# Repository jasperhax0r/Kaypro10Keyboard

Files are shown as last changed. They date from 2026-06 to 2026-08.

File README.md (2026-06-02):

# Kaypro 10 Replacement Keyboard

A modern replacement keyboard for the Kaypro 10 that fits the original case, using Cherry MX-style switches and a Raspberry Pi Pico running MicroPython to emulate the original 300 baud serial keyboard interface.

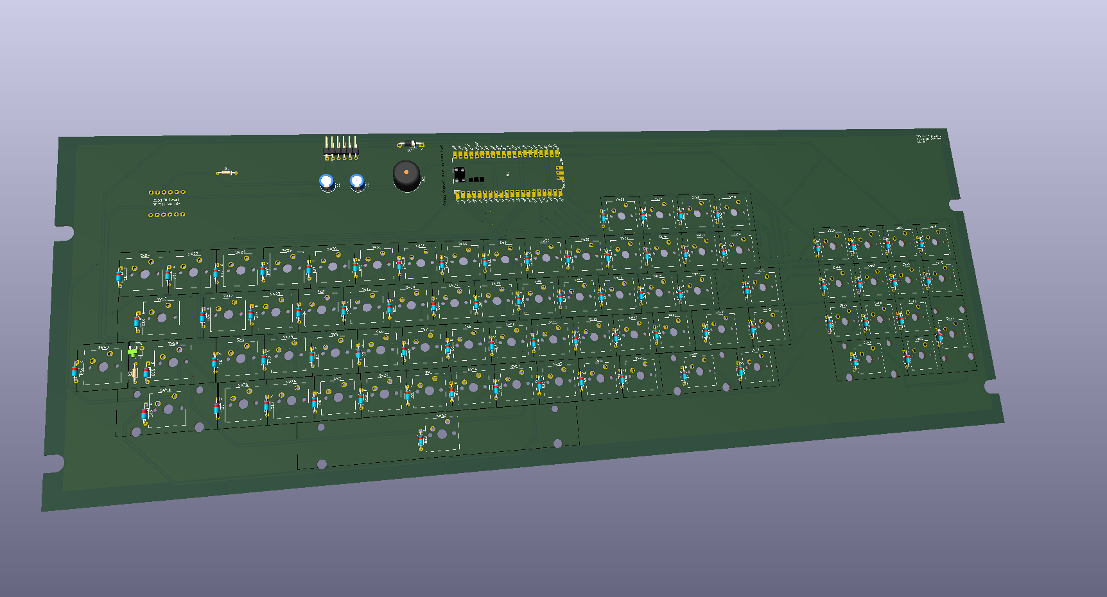
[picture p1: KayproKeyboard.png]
Kaypro Keyboard PCB


*KiCad 3D render of the PCB*

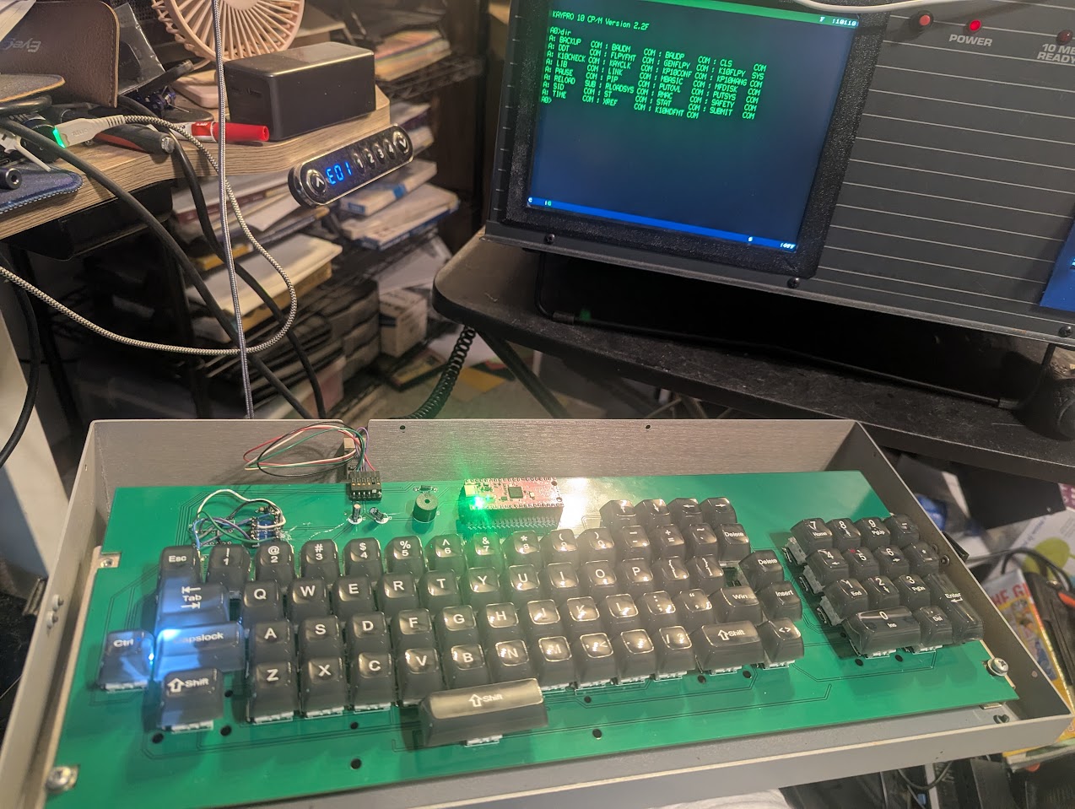
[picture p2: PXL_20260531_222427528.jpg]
Prototype Working


*Prototype board installed and working*

---

## Overview

The original Kaypro 10 keyboard is increasingly difficult to find in working condition. This project provides a drop-in replacement that:

- Fits the original Kaypro 10 keyboard case with no modifications
- Uses modern Cherry MX-style mechanical switches
- Communicates over the Kaypro's original 300 baud serial keyboard interface
- Is driven by a Raspberry Pi Pico running MicroPython
- Includes a 3D printed switch support plate (no metal plate in this design)

---

## Repository Contents

All files are in the root of the repository.

| File | Description |
|---|---|
| `*.kicad_pro`, `*.kicad_sch`, `*.kicad_pcb`, etc. | KiCad 10 schematic and PCB design files |
| `KayproKeyboard.zip` | Generated Gerber/manufacturing files, ready to send to a PCB fab |
| `KayproKeyboard.png` | KiCad 3D render of the board |
| `keyboard support.stl` | 3D printable switch support plate |
| `main.py` | MicroPython firmware for the Raspberry Pi Pico |
| `PXL_20260531_222427528.jpg` | Photo of the working prototype |

---

## Bill of Materials

| Qty | Component | Notes |
|-----|---|---|
| 76 | 1N4148 diode | One per switch, for key matrix decoding |
| 76 | Cherry MX-style switches | One per key position |
| — | PCB-mount stabilizers | Required for larger keys (spacebar, shift, enter, etc.) — quantity depends on layout |
| 1 | Waveshare BS138 4-channel bidirectional level shifter module | 3.3V ↔ 5V logic level conversion |
| 1 | Passive buzzer/speaker | Key click feedback |
| 1 | LED (single, any color) | Status indicator |
| 1 | 330Ω resistor | LED current limiting |
| 1 | 47kΩ resistor | Pull-up/pull-down for serial line |
| 1 | Protection diode | 5V input protection for the Pico |
| 1 | Raspberry Pi Pico | Main controller (standard Pico, not Pico W) |
| 1 | 6-pin horizontal header | Serial interface connector to Kaypro mainboard |

> **Note:** Use 1N4148 diodes (or equivalent) for the key matrix. One diode is required per switch to prevent ghosting.

---

## PCB Manufacturing

The file `KayproKeyboard.zip` contains all Gerber files needed for fabrication. It can be uploaded directly to most PCB manufacturers (JLCPCB, PCBWay, OSHPark, etc.) without modification.

Recommended specs:
- **Layers:** 2
- **Thickness:** 1.6mm
- **Surface finish:** HASL or ENIG

---

## 3D Printed Support

Because this design does not use a metal switch plate, a 3D printed support structure (`keyboard support.stl`) is included to provide rigidity and hold the switches in alignment during soldering and use.

Print in PLA or PETG at 0.2mm layer height with at least 20% infill. No supports should be needed.

---

## Firmware

The Pico runs MicroPython. Copy `main.py` to the Pico's root filesystem and it will start automatically on boot.

### Flashing the Pico

1. Hold the BOOTSEL button and connect the Pico to your computer via USB.
2. It will appear as a USB mass storage device (`RPI-RP2`).
3. Flash the latest [MicroPython UF2](https://micropython.org/download/rp2-pico/) by dragging it onto the drive.
4. Once rebooted, use a tool like [Thonny](https://thonny.org/) or `mpremote` to copy `main.py` to the Pico:
   ```
   mpremote cp main.py :main.py
   ```

The firmware reads the key matrix, debounces inputs, and outputs the correct character codes over the serial interface at 300 baud to match the Kaypro's original keyboard protocol.

---

## Connector Pinout

The keyboard connects to the Kaypro 10 mainboard via a 6-pin horizontal header. Pinout, numbered left to right:

| Pin | Signal | Description |
|-----|---|---|
| 1 | 5V | Power from Kaypro mainboard |
| 2 | TX | Serial data out — keyboard → Kaypro, 300 baud |
| 3 | GND | Ground |
| 4 | GND | Ground |
| 5 | — | Missing/keyed pin (no connection) |
| 6 | RX | Serial data in — Kaypro → keyboard, 300 baud |

> ⚠️ **Important:** This pinout was determined from an **1983-spec Kaypro 10**. It may not be universal across all Kaypro models or revisions. Verify against your own machine before connecting. The protection diode on the 5V input and the BS138 level shifter are strongly recommended to avoid damaging the Pico.

The BS138 level shifter module handles 3.3V Pico ↔ 5V Kaypro logic translation on the TX and RX lines.

---

## Design Files

Schematics and PCB layout were created in **KiCad 10**. The KiCad project files are in the root directory and can be opened and modified freely.

---

## License

This project is open source. Schematics, PCB files, firmware, and mechanical files are provided as-is for personal and educational use.

Contributions, improvements, and ports to other Kaypro models are welcome — open a PR or issue!

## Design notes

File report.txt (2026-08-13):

Info: X scale constrained.
Info: Y scale constrained.
Plotted to 'C:\Users\Jasper\Desktop\Projects\Kaypro10\3D Prints and PCBs\KayproKeyboard\KayproKeyboard-F_Cu.gbr'.
Plotted to 'C:\Users\Jasper\Desktop\Projects\Kaypro10\3D Prints and PCBs\KayproKeyboard\KayproKeyboard-B_Cu.gbr'.
Plotted to 'C:\Users\Jasper\Desktop\Projects\Kaypro10\3D Prints and PCBs\KayproKeyboard\KayproKeyboard-F_Paste.gbr'.
Plotted to 'C:\Users\Jasper\Desktop\Projects\Kaypro10\3D Prints and PCBs\KayproKeyboard\KayproKeyboard-B_Paste.gbr'.
Plotted to 'C:\Users\Jasper\Desktop\Projects\Kaypro10\3D Prints and PCBs\KayproKeyboard\KayproKeyboard-F_Silkscreen.gbr'.
Plotted to 'C:\Users\Jasper\Desktop\Projects\Kaypro10\3D Prints and PCBs\KayproKeyboard\KayproKeyboard-B_Silkscreen.gbr'.
Plotted to 'C:\Users\Jasper\Desktop\Projects\Kaypro10\3D Prints and PCBs\KayproKeyboard\KayproKeyboard-F_Mask.gbr'.
Plotted to 'C:\Users\Jasper\Desktop\Projects\Kaypro10\3D Prints and PCBs\KayproKeyboard\KayproKeyboard-B_Mask.gbr'.
Plotted to 'C:\Users\Jasper\Desktop\Projects\Kaypro10\3D Prints and PCBs\KayproKeyboard\KayproKeyboard-Edge_Cuts.gbr'.
Created Gerber job file 'C:\Users\Jasper\Desktop\Projects\Kaypro10\3D Prints and PCBs\KayproKeyboard\KayproKeyboard-job.gbrjob'.
Info: Done.

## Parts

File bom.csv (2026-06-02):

Designator | Footprint | Quantity | Value | LCSC Part #
BZ1 | Buzzer_12x9.5RM7.6 | 1 | Buzzer
C1, C2 | CP_Radial_D6.3mm_P2.50mm | 2 | C_Polarized_US
D1, D10, D11, D12, D13, D14, D15, D16, D17, D18, D19, D2, D20, D21, D22, D23, D24, D25, D26, D27, D28, D29, D3, D30, D31, D32, D33, D34, D35, D36, D37, D38, D39, D4, D40, D41, D42, D43, D44, D45, D46, D47, D48, D49, D5, D50, D51, D52, D53, D54, D55, D56, D57, D58, D59, D6, D60, D61, D62, D63, D64, D65, D66, D67, D68, D69, D7, D70, D71, D72, D73, D74, D75, D78, D8, D9 | D_DO-35_SOD27_P7.62mm_Horizontal | 76 | 1N4148
D76 | LED_D1.8mm_W1.8mm_H2.4mm_Horizontal_O1.27mm_Z4.9mm | 1 | CAPSLED
D77 | D_DO-41_SOD81_P10.16mm_Horizontal | 1 | 1N5817
J1 | PinHeader_1x06_P2.54mm_Horizontal | 1 | Conn_01x06_Pin
J2, J3 | 1x06_P2.54mm | 2 | Conn_01x06
R1 | R_Axial_DIN0204_L3.6mm_D1.6mm_P7.62mm_Horizontal | 1 | 4.7K
R2 | R_Axial_DIN0204_L3.6mm_D1.6mm_P7.62mm_Horizontal | 1 | 330
SW1 | SW_Cherry_MX_1.00u_PCB | 1 | A_Key
SW10 | SW_Cherry_MX_1.00u_PCB | 1 | J_Key
SW11 | SW_Cherry_MX_1.00u_PCB | 1 | K_Key
SW12 | SW_Cherry_MX_1.00u_PCB | 1 | L_Key
SW13 | SW_Cherry_MX_1.00u_PCB | 1 | M_Key
SW14 | SW_Cherry_MX_1.00u_PCB | 1 | N_Key
SW15 | SW_Cherry_MX_1.00u_PCB | 1 | O_Key
SW16 | SW_Cherry_MX_1.00u_PCB | 1 | P_Key
SW17 | SW_Cherry_MX_1.00u_PCB | 1 | Q_Key
SW18 | SW_Cherry_MX_1.00u_PCB | 1 | R_Key
SW19 | SW_Cherry_MX_1.00u_PCB | 1 | S_Key
SW2 | SW_Cherry_MX_1.00u_PCB | 1 | B_Key
SW20 | SW_Cherry_MX_1.00u_PCB | 1 | T_Key
SW21 | SW_Cherry_MX_1.00u_PCB | 1 | U_Key
SW22 | SW_Cherry_MX_1.00u_PCB | 1 | V_Key
SW23 | SW_Cherry_MX_1.00u_PCB | 1 | W_Key
SW24 | SW_Cherry_MX_1.00u_PCB | 1 | X_Key
SW25 | SW_Cherry_MX_1.00u_PCB | 1 | Y_Key
SW26 | SW_Cherry_MX_1.00u_PCB | 1 | Z_Key
SW27 | SW_Cherry_MX_1.00u_PCB | 1 | 1_Key
SW28 | SW_Cherry_MX_1.00u_PCB | 1 | 2_Key
SW29 | SW_Cherry_MX_1.00u_PCB | 1 | 3_Key
SW3 | SW_Cherry_MX_1.00u_PCB | 1 | C_Key
SW30 | SW_Cherry_MX_1.00u_PCB | 1 | 4_Key
SW31 | SW_Cherry_MX_1.00u_PCB | 1 | 5_Key
SW32 | SW_Cherry_MX_1.00u_PCB | 1 | 6_Key
SW33 | SW_Cherry_MX_1.00u_PCB | 1 | 7_Key
SW34 | SW_Cherry_MX_1.00u_PCB | 1 | 8_Key
SW35 | SW_Cherry_MX_1.00u_PCB | 1 | 9_Key
SW36 | SW_Cherry_MX_1.00u_PCB | 1 | 0_Key
SW37 | SW_Cherry_MX_1.00u_PCB | 1 | -_Key
SW38 | SW_Cherry_MX_1.00u_PCB | 1 | =_Key
SW39 | SW_Cherry_MX_1.00u_PCB | 1 | `_Key
SW4 | SW_Cherry_MX_1.00u_PCB | 1 | D_Key
SW40 | SW_Cherry_MX_1.00u_PCB | 1 | ;_Key
SW41 | SW_Cherry_MX_1.00u_PCB | 1 | '_Key
SW42 | SW_Cherry_MX_1.00u_PCB | 1 | \_Key
SW43 | SW_Cherry_MX_1.00u_PCB | 1 | ,_Key
SW44 | SW_Cherry_MX_1.00u_PCB | 1 | ._Key
SW45 | SW_Cherry_MX_1.00u_PCB | 1 | /_Key
SW46 | SW_Cherry_MX_2.00u_PCB | 1 | LSHIFT_Key
SW47 | SW_Cherry_MX_2.00u_PCB | 1 | RSHIFT_Key
SW49 | SW_Cherry_MX_1.00u_PCB | 1 | CTRL_Key
SW5 | SW_Cherry_MX_1.00u_PCB | 1 | E_Key
SW50 | SW_Cherry_MX_1.75u_PCB | 1 | CAPS_Key
SW51 | SW_Cherry_MX_1.00u_PCB | 1 | DEL_Key
SW52 | SW_Cherry_MX_1.00u_PCB | 1 | BACKSPACE_Key
SW53 | SW_Cherry_MX_6.25u_PCB | 1 | SPACE_Key
SW54 | SW_Cherry_MX_1.00u_PCB | 1 | ESC_Key
SW55 | SW_Cherry_MX_1.75u_PCB | 1 | TAB_Key
SW56 | SW_Cherry_MX_1.50u_PCB | 1 | RETURN_Key
SW57 | SW_Cherry_MX_1.00u_PCB | 1 | LINEFEED_Key
SW58 | SW_Cherry_MX_1.00u_PCB | 1 | UP_Key
SW59 | SW_Cherry_MX_1.00u_PCB | 1 | DOWN_Key
SW6 | SW_Cherry_MX_1.00u_PCB | 1 | F_Key
SW60 | SW_Cherry_MX_1.00u_PCB | 1 | LEFT_Key
SW61 | SW_Cherry_MX_1.00u_PCB | 1 | RIGHT_Key
SW62 | SW_Cherry_MX_2.00u_PCB | 1 | NUM0_Key
SW63 | SW_Cherry_MX_1.00u_PCB | 1 | NUM1_Key
SW64 | SW_Cherry_MX_1.00u_PCB | 1 | NUM2_Key
SW65 | SW_Cherry_MX_1.00u_PCB | 1 | NUM3_Key
SW66 | SW_Cherry_MX_1.00u_PCB | 1 | NUM4_Key
SW67 | SW_Cherry_MX_1.00u_PCB | 1 | NUM5_Key
SW68 | SW_Cherry_MX_1.00u_PCB | 1 | NUM6_Key
SW69 | SW_Cherry_MX_1.00u_PCB | 1 | NUM7_Key
SW7 | SW_Cherry_MX_1.00u_PCB | 1 | G_Key
SW70 | SW_Cherry_MX_1.00u_PCB | 1 | NUM8_Key
SW71 | SW_Cherry_MX_1.00u_PCB | 1 | NUM9_Key
SW72 | SW_Cherry_MX_1.00u_PCB | 1 | NUM._Key
SW73 | SW_Cherry_MX_2.00u_Vertical_PCB | 1 | NUMENTER_Key
SW74 | SW_Cherry_MX_1.00u_PCB | 1 | NUM-_Key
SW75 | SW_Cherry_MX_1.00u_PCB | 1 | NUM,_Key
SW76 | SW_Cherry_MX_1.00u_PCB | 1 | [_KEY
SW77 | SW_Cherry_MX_1.00u_PCB | 1 | ]_KEY
SW8 | SW_Cherry_MX_1.00u_PCB | 1 | H_Key
SW9 | SW_Cherry_MX_1.00u_PCB | 1 | I_Key
U1 | RPi_Pico_SMD_TH | 1 | Pico

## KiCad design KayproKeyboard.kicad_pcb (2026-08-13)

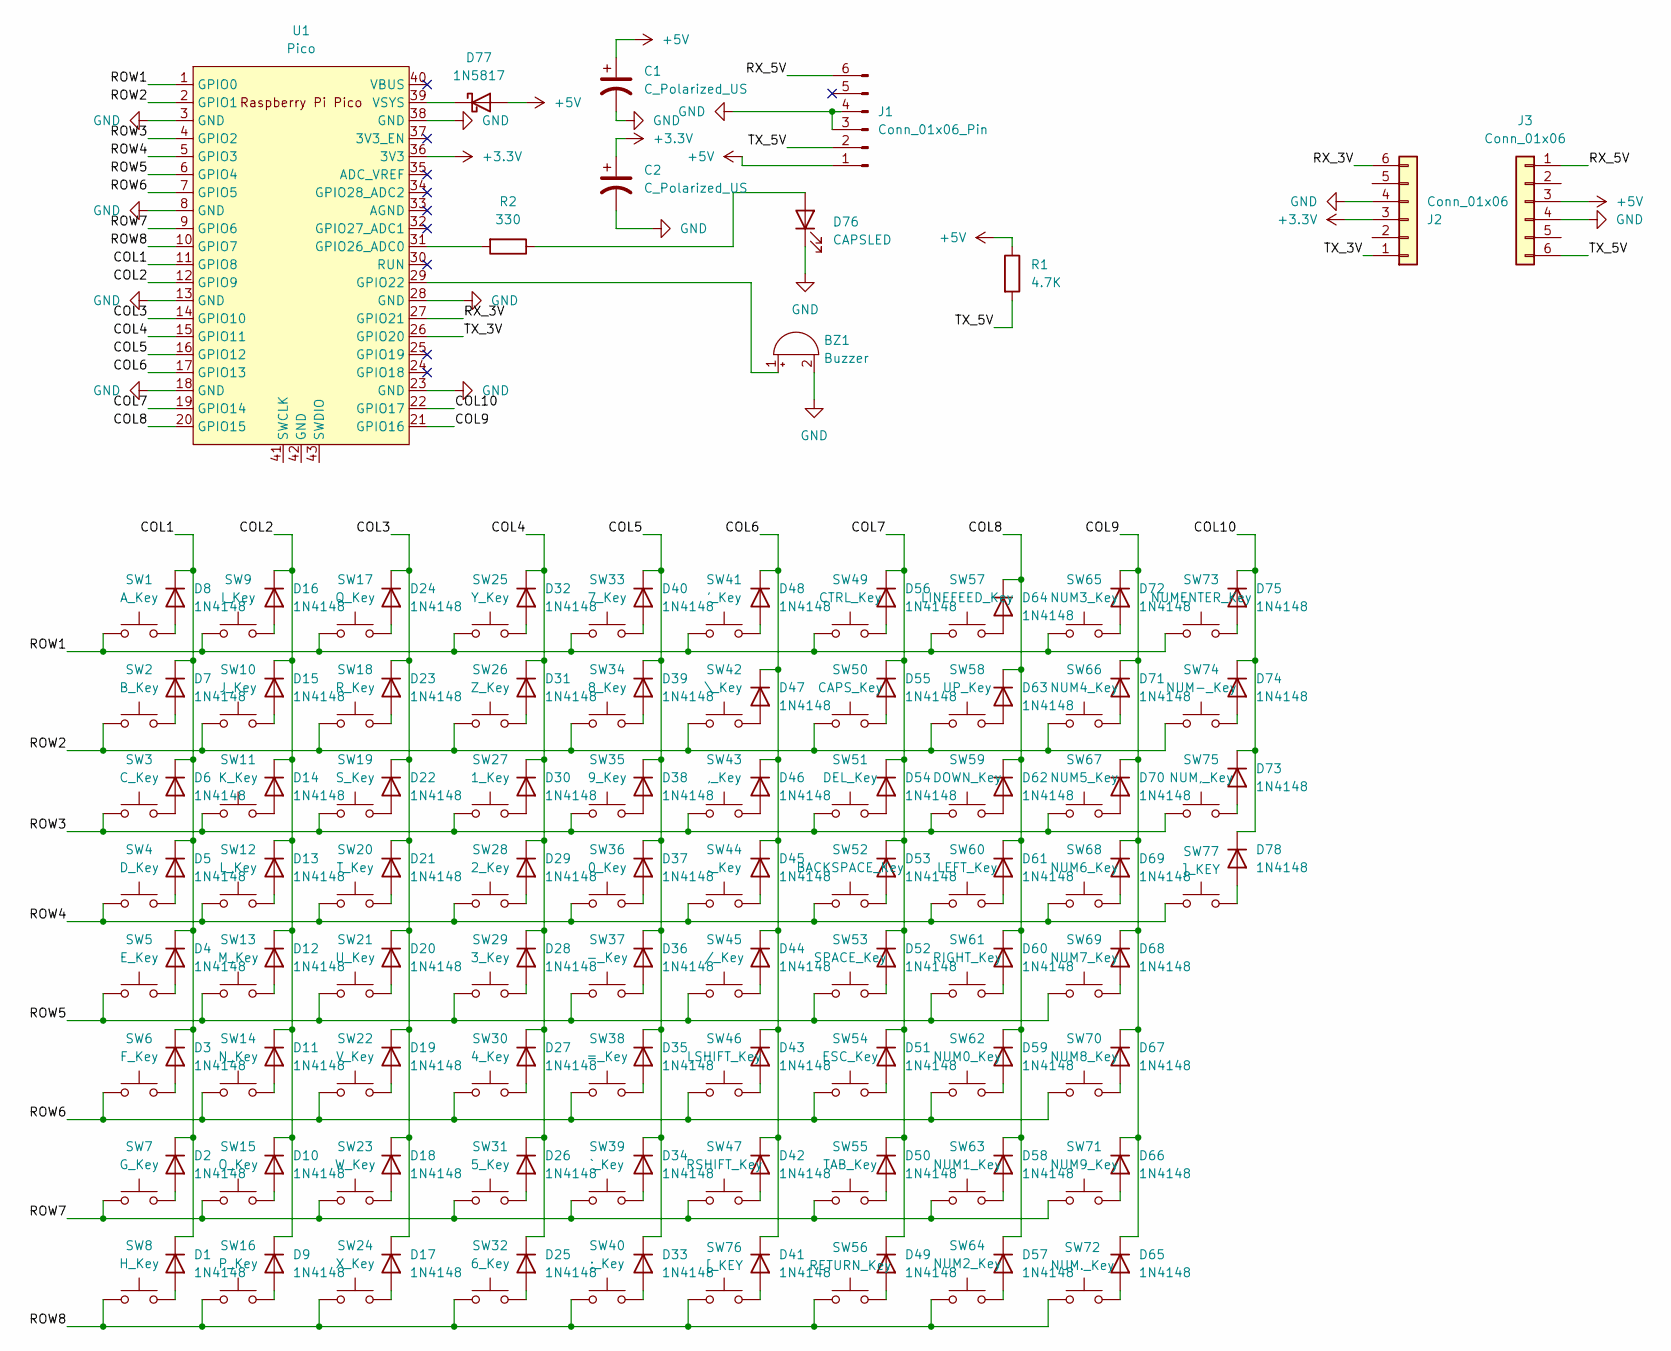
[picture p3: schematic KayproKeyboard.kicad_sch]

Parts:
BZ1: Buzzer; Buzzer_12x9.5RM7.6
C1, C2: C_Polarized_US; CP_Radial_D6.3mm_P2.50mm
D1, D2, D3, D4, D5, D6, D7, D8, D9, D10, D11, D12, D13, D14, D15, D16, D17, D18, D19, D20, D21, D22, D23, D24, D25, D26, D27, D28, D29, D30, D31, D32, D33, D34, D35, D36, D37, D38, D39, D40, D41, D42, D43, D44, D45, D46, D47, D48, D49, D50, D51, D52, D53, D54, D55, D56, D57, D58, D59, D60, D61, D62, D63, D64, D65, D66, D67, D68, D69, D70, D71, D72, D73, D74, D75, D78: 1N4148; D_DO-35_SOD27_P7.62mm_Horizontal
D76: CAPSLED; LED_D1.8mm_W1.8mm_H2.4mm_Horizontal_O1.27mm_Z4.9mm
D77: 1N5817; D_DO-41_SOD81_P10.16mm_Horizontal
J1: Conn_01x06_Pin; PinHeader_1x06_P2.54mm_Horizontal
J2, J3: Conn_01x06; 1x06_P2.54mm
R1: 4.7K; R_Axial_DIN0204_L3.6mm_D1.6mm_P7.62mm_Horizontal
R2: 330; R_Axial_DIN0204_L3.6mm_D1.6mm_P7.62mm_Horizontal
SW1: A_Key; SW_Cherry_MX_1.00u_PCB
SW2: B_Key; SW_Cherry_MX_1.00u_PCB
SW3: C_Key; SW_Cherry_MX_1.00u_PCB
SW4: D_Key; SW_Cherry_MX_1.00u_PCB
SW5: E_Key; SW_Cherry_MX_1.00u_PCB
SW6: F_Key; SW_Cherry_MX_1.00u_PCB
SW7: G_Key; SW_Cherry_MX_1.00u_PCB
SW8: H_Key; SW_Cherry_MX_1.00u_PCB
SW9: I_Key; SW_Cherry_MX_1.00u_PCB
SW10: J_Key; SW_Cherry_MX_1.00u_PCB
SW11: K_Key; SW_Cherry_MX_1.00u_PCB
SW12: L_Key; SW_Cherry_MX_1.00u_PCB
SW13: M_Key; SW_Cherry_MX_1.00u_PCB
SW14: N_Key; SW_Cherry_MX_1.00u_PCB
SW15: O_Key; SW_Cherry_MX_1.00u_PCB
SW16: P_Key; SW_Cherry_MX_1.00u_PCB
SW17: Q_Key; SW_Cherry_MX_1.00u_PCB
SW18: R_Key; SW_Cherry_MX_1.00u_PCB
SW19: S_Key; SW_Cherry_MX_1.00u_PCB
SW20: T_Key; SW_Cherry_MX_1.00u_PCB
SW21: U_Key; SW_Cherry_MX_1.00u_PCB
SW22: V_Key; SW_Cherry_MX_1.00u_PCB
SW23: W_Key; SW_Cherry_MX_1.00u_PCB
SW24: X_Key; SW_Cherry_MX_1.00u_PCB
SW25: Y_Key; SW_Cherry_MX_1.00u_PCB
SW26: Z_Key; SW_Cherry_MX_1.00u_PCB
SW27: 1_Key; SW_Cherry_MX_1.00u_PCB
SW28: 2_Key; SW_Cherry_MX_1.00u_PCB
SW29: 3_Key; SW_Cherry_MX_1.00u_PCB
SW30: 4_Key; SW_Cherry_MX_1.00u_PCB
SW31: 5_Key; SW_Cherry_MX_1.00u_PCB
SW32: 6_Key; SW_Cherry_MX_1.00u_PCB
SW33: 7_Key; SW_Cherry_MX_1.00u_PCB
SW34: 8_Key; SW_Cherry_MX_1.00u_PCB
SW35: 9_Key; SW_Cherry_MX_1.00u_PCB
SW36: 0_Key; SW_Cherry_MX_1.00u_PCB
SW37: -_Key; SW_Cherry_MX_1.00u_PCB
SW38: =_Key; SW_Cherry_MX_1.00u_PCB
SW39: `_Key; SW_Cherry_MX_1.00u_PCB
SW40: ;_Key; SW_Cherry_MX_1.00u_PCB
SW41: '_Key; SW_Cherry_MX_1.00u_PCB
SW42: \_Key; SW_Cherry_MX_1.00u_PCB
SW43: ,_Key; SW_Cherry_MX_1.00u_PCB
SW44: ._Key; SW_Cherry_MX_1.00u_PCB
SW45: /_Key; SW_Cherry_MX_1.00u_PCB
SW46: LSHIFT_Key; SW_Cherry_MX_2.00u_PCB
SW47: RSHIFT_Key; SW_Cherry_MX_2.00u_PCB
SW49: CTRL_Key; SW_Cherry_MX_1.00u_PCB
SW50: CAPS_Key; SW_Cherry_MX_1.75u_PCB
SW51: DEL_Key; SW_Cherry_MX_1.00u_PCB
SW52: BACKSPACE_Key; SW_Cherry_MX_1.00u_PCB
SW53: SPACE_Key; SW_Cherry_MX_6.25u_PCB
SW54: ESC_Key; SW_Cherry_MX_1.00u_PCB
SW55: TAB_Key; SW_Cherry_MX_1.75u_PCB
SW56: RETURN_Key; SW_Cherry_MX_1.50u_PCB
SW57: LINEFEED_Key; SW_Cherry_MX_1.00u_PCB
SW58: UP_Key; SW_Cherry_MX_1.00u_PCB
SW59: DOWN_Key; SW_Cherry_MX_1.00u_PCB
SW60: LEFT_Key; SW_Cherry_MX_1.00u_PCB
SW61: RIGHT_Key; SW_Cherry_MX_1.00u_PCB
SW62: NUM0_Key; SW_Cherry_MX_2.00u_PCB
SW63: NUM1_Key; SW_Cherry_MX_1.00u_PCB
SW64: NUM2_Key; SW_Cherry_MX_1.00u_PCB
SW65: NUM3_Key; SW_Cherry_MX_1.00u_PCB
SW66: NUM4_Key; SW_Cherry_MX_1.00u_PCB
SW67: NUM5_Key; SW_Cherry_MX_1.00u_PCB
SW68: NUM6_Key; SW_Cherry_MX_1.00u_PCB
SW69: NUM7_Key; SW_Cherry_MX_1.00u_PCB
SW70: NUM8_Key; SW_Cherry_MX_1.00u_PCB
SW71: NUM9_Key; SW_Cherry_MX_1.00u_PCB
SW72: NUM._Key; SW_Cherry_MX_1.00u_PCB
SW73: NUMENTER_Key; SW_Cherry_MX_2.00u_Vertical_PCB
SW74: NUM-_Key; SW_Cherry_MX_1.00u_PCB
SW75: NUM,_Key; SW_Cherry_MX_1.00u_PCB
SW76: [_KEY; SW_Cherry_MX_1.00u_PCB
SW77: ]_KEY; SW_Cherry_MX_1.00u_PCB
U1: Pico; RPi_Pico_SMD_TH

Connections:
+3.3V: C2.1, J2.3, U1.36 (3V3)
+5V: C1.1, D77.2 (A), J1.1, J3.3, R1.1
/COL1: D1.1 (K), D2.1 (K), D3.1 (K), D4.1 (K), D5.1 (K), D6.1 (K), D7.1 (K), D8.1 (K), U1.11 (GPIO8)
/COL2: D9.1 (K), D10.1 (K), D11.1 (K), D12.1 (K), D13.1 (K), D14.1 (K), D15.1 (K), D16.1 (K), U1.12 (GPIO9)
/COL3: D17.1 (K), D18.1 (K), D19.1 (K), D20.1 (K), D21.1 (K), D22.1 (K), D23.1 (K), D24.1 (K), U1.14 (GPIO10)
/COL4: D25.1 (K), D26.1 (K), D27.1 (K), D28.1 (K), D29.1 (K), D30.1 (K), D31.1 (K), D32.1 (K), U1.15 (GPIO11)
/COL5: D33.1 (K), D34.1 (K), D35.1 (K), D36.1 (K), D37.1 (K), D38.1 (K), D39.1 (K), D40.1 (K), U1.16 (GPIO12)
/COL6: D41.1 (K), D42.1 (K), D43.1 (K), D44.1 (K), D45.1 (K), D46.1 (K), D47.1 (K), D48.1 (K), U1.17 (GPIO13)
/COL7: D49.1 (K), D50.1 (K), D51.1 (K), D52.1 (K), D53.1 (K), D54.1 (K), D55.1 (K), D56.1 (K), U1.19 (GPIO14)
/COL8: D57.1 (K), D58.1 (K), D59.1 (K), D60.1 (K), D61.1 (K), D62.1 (K), D63.1 (K), D64.1 (K), U1.20 (GPIO15)
/COL9: D65.1 (K), D66.1 (K), D67.1 (K), D68.1 (K), D69.1 (K), D70.1 (K), D71.1 (K), D72.1 (K), U1.21 (GPIO16)
/COL10: D73.1 (K), D74.1 (K), D75.1 (K), D78.1 (K), U1.22 (GPIO17)
/ROW1: SW1.1, SW9.1, SW17.1, SW25.1, SW33.1, SW41.1, SW49.1, SW57.1, SW65.1, SW73.1, U1.1 (GPIO0)
/ROW2: SW2.1, SW10.1, SW18.1, SW26.1, SW34.1, SW42.1, SW50.1, SW58.1, SW66.1, SW74.1, U1.2 (GPIO1)
/ROW3: SW3.1, SW11.1, SW19.1, SW27.1, SW35.1, SW43.1, SW51.1, SW59.1, SW67.1, SW75.1, U1.4 (GPIO2)
/ROW4: SW4.1, SW12.1, SW20.1, SW28.1, SW36.1, SW44.1, SW52.1, SW60.1, SW68.1, SW77.1, U1.5 (GPIO3)
/ROW5: SW5.1, SW13.1, SW21.1, SW29.1, SW37.1, SW45.1, SW53.1, SW61.1, SW69.1, U1.6 (GPIO4)
/ROW6: SW6.1, SW14.1, SW22.1, SW30.1, SW38.1, SW46.1, SW54.1, SW62.1, SW70.1, U1.7 (GPIO5)
/ROW7: SW7.1, SW15.1, SW23.1, SW31.1, SW39.1, SW47.1, SW55.1, SW63.1, SW71.1, U1.9 (GPIO6)
/ROW8: SW8.1, SW16.1, SW24.1, SW32.1, SW40.1, SW56.1, SW64.1, SW72.1, SW76.1, U1.10 (GPIO7)
/RX_3V: J2.6, U1.27 (GPIO21)
/RX_5V: J1.6, J3.1
/TX_3V: J2.1, U1.26 (GPIO20)
/TX_5V: J1.2, J3.6, R1.2
GND: BZ1.2 (-), C1.2, C2.2, D76.1 (K), J1.3, J1.4, J2.4, J3.4, U1.3 (GND), U1.8 (GND), U1.13 (GND), U1.18 (GND), U1.23 (GND), U1.28 (GND), U1.38 (GND)
unnamed: BZ1.1 (+), U1.29 (GPIO22)
unnamed: D1.2 (A), SW8.2
unnamed: D2.2 (A), SW7.2
unnamed: D3.2 (A), SW6.2
unnamed: D4.2 (A), SW5.2
unnamed: D5.2 (A), SW4.2
unnamed: D6.2 (A), SW3.2
unnamed: D7.2 (A), SW2.2
unnamed: D8.2 (A), SW1.2
unnamed: D9.2 (A), SW16.2
unnamed: D10.2 (A), SW15.2
unnamed: D11.2 (A), SW14.2
unnamed: D12.2 (A), SW13.2
unnamed: D13.2 (A), SW12.2
unnamed: D14.2 (A), SW11.2
unnamed: D15.2 (A), SW10.2
unnamed: D16.2 (A), SW9.2
unnamed: D17.2 (A), SW24.2
unnamed: D18.2 (A), SW23.2
unnamed: D19.2 (A), SW22.2
unnamed: D20.2 (A), SW21.2
unnamed: D21.2 (A), SW20.2
unnamed: D22.2 (A), SW19.2
unnamed: D23.2 (A), SW18.2
unnamed: D24.2 (A), SW17.2
unnamed: D25.2 (A), SW32.2
unnamed: D26.2 (A), SW31.2
unnamed: D27.2 (A), SW30.2
unnamed: D28.2 (A), SW29.2
unnamed: D29.2 (A), SW28.2
unnamed: D30.2 (A), SW27.2
unnamed: D31.2 (A), SW26.2
unnamed: D32.2 (A), SW25.2
unnamed: D33.2 (A), SW40.2
unnamed: D34.2 (A), SW39.2
unnamed: D35.2 (A), SW38.2
unnamed: D36.2 (A), SW37.2
unnamed: D37.2 (A), SW36.2
unnamed: D38.2 (A), SW35.2
unnamed: D39.2 (A), SW34.2
unnamed: D40.2 (A), SW33.2
unnamed: D41.2 (A), SW76.2
unnamed: D42.2 (A), SW47.2
unnamed: D43.2 (A), SW46.2
unnamed: D44.2 (A), SW45.2
unnamed: D45.2 (A), SW44.2
unnamed: D46.2 (A), SW43.2
unnamed: D47.2 (A), SW42.2
unnamed: D48.2 (A), SW41.2
unnamed: D49.2 (A), SW56.2
unnamed: D50.2 (A), SW55.2
unnamed: D51.2 (A), SW54.2
unnamed: D52.2 (A), SW53.2
unnamed: D53.2 (A), SW52.2
unnamed: D54.2 (A), SW51.2
unnamed: D55.2 (A), SW50.2
unnamed: D56.2 (A), SW49.2
unnamed: D57.2 (A), SW64.2
unnamed: D58.2 (A), SW63.2
unnamed: D59.2 (A), SW62.2
unnamed: D60.2 (A), SW61.2
unnamed: D61.2 (A), SW60.2
unnamed: D62.2 (A), SW59.2
unnamed: D63.2 (A), SW58.2
unnamed: D64.2 (A), SW57.2
unnamed: D65.2 (A), SW72.2
unnamed: D66.2 (A), SW71.2
unnamed: D67.2 (A), SW70.2
unnamed: D68.2 (A), SW69.2
unnamed: D69.2 (A), SW68.2
unnamed: D70.2 (A), SW67.2
unnamed: D71.2 (A), SW66.2
unnamed: D72.2 (A), SW65.2
unnamed: D73.2 (A), SW75.2
unnamed: D74.2 (A), SW74.2
unnamed: D75.2 (A), SW73.2
unnamed: D76.2 (A), R2.1
unnamed: D77.1 (K), U1.39 (VSYS)
unnamed: D78.2 (A), SW77.2
unnamed: R2.2, U1.31 (GPIO26_ADC0)

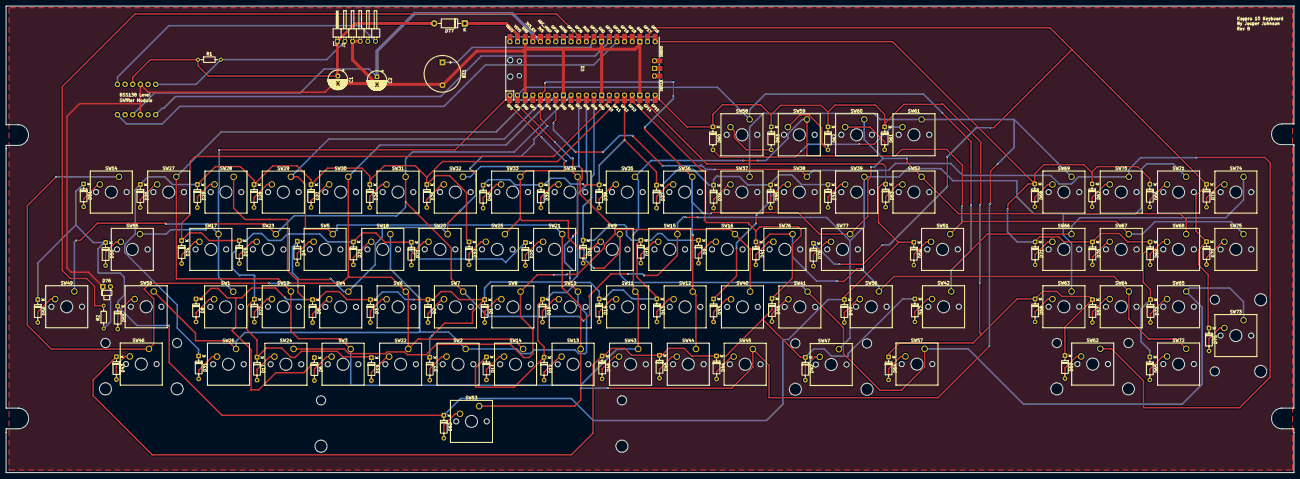
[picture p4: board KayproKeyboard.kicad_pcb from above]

Board: 2 copper layers, 427.9 x 155.0 mm, 163 parts (0 on the bottom side), 105 nets.

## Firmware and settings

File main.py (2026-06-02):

from machine import Pin
import time

# ==========================================================
# MATRIX CONFIGURATION
# ==========================================================

ROW_PINS = [0, 1, 2, 3, 4, 5, 6, 7]
COL_PINS = [8, 9, 10, 11, 12, 13, 14, 15, 16, 17]

DEBOUNCE_MS = 20
SCAN_DELAY_US = 50


KEYMAP = [
    ["A", "I", "Q", "Y", "7", "'", "CTRL", "LINEFEED", "3", "RETURN"],
    ["B", "J", "R", "Z", "8", "\\", "CAPS", "UP", "4", "-"],
    ["C", "K", "S", "1", "9", ",", "DEL", "DOWN", "5", "'"],
    ["D", "L", "T", "2", "0", ".", "BACKSPACE", "LEFT", "6", "]"],
    ["E", "M", "U", "3", "-", "/", "SPACE", "RIGHT", "7", None],
    ["F", "N", "V", "4", "=", "LSHIFT", "ESC", "0", "8", None],
    ["G", "O", "W", "5", "`", "RSHIFT", "TAB", "1", "9", None],
    ["H", "P", "X", "6", ";", "[", "RETURN", "2", ".", None],
]

# ==========================================================
# UART
# ==========================================================

from machine import UART

kaypro_uart = UART(
    1,
    baudrate=300,
    tx=Pin(20),
    rx=Pin(21)
)

# ==========================================================
# STATUS LED / CAPS LED / BUZZER
# ==========================================================

# Pico onboard LED
power_led = Pin("LED", Pin.OUT)
power_led.value(1)   # ON whenever keyboard powered

# Caps Lock LED
caps_led = Pin(26, Pin.OUT)
caps_led.value(0)

# Buzzer
buzzer = Pin(22, Pin.OUT)
buzzer.value(0)

# ==========================================================
# MODIFIER STATE
# ==========================================================

shift_active = False
ctrl_active = False
caps_lock = False


# ==========================================================
# SHIFT SYMBOL MAP
# ==========================================================

SHIFT_MAP = {
    "1": "!",
    "2": "@",
    "3": "#",
    "4": "$",
    "5": "%",
    "6": "^",
    "7": "&",
    "8": "*",
    "9": "(",
    "0": ")",

    "-": "_",
    "=": "+",
    "`": "~",

    "[": "{",
    "]": "}",

    ";": ":",
    "'": "\"",

    ",": "<",
    ".": ">",
    "/": "?",

    "\\": "|"
}

# ==========================================================
# GPIO SETUP
# ==========================================================

# Rows = outputs
rows = []
for pin_num in ROW_PINS:
    pin = Pin(pin_num, Pin.OUT)
    pin.value(1)  # idle HIGH
    rows.append(pin)

# Columns = inputs with pullups
cols = []
for pin_num in COL_PINS:
    pin = Pin(pin_num, Pin.IN, Pin.PULL_UP)
    cols.append(pin)

# ==========================================================
# STATE TRACKING
# ==========================================================

stable_keys = set()
candidate_keys = set()

last_change_time = time.ticks_ms()

# ==========================================================
# KEY PROCESSING
# ==========================================================

def send_key(key):

    global shift_active
    global ctrl_active
    global caps_lock

    # ----------------------------------
    # Ignore modifier keys themselves
    # ----------------------------------

    if key in ("LSHIFT", "RSHIFT", "CTRL", "CAPS"):
        return

    # ----------------------------------
    # Special keys
    # ----------------------------------

    special = {
        "RETURN": "\r",
        "LINEFEED": "\n",
        "BACKSPACE": "\b",
        "TAB": "\t",
        "ESC": chr(27),
        "SPACE": " ",
        "DEL": chr(127),
    }

    if key in special:
        kaypro_uart.write(special[key])
        print("TX:", repr(special[key]))
        return

    # ----------------------------------
    # CTRL handling
    # ----------------------------------

    if ctrl_active and len(key) == 1 and key.isalpha():

        ctrl_code = ord(key.upper()) - 64

        kaypro_uart.write(bytes([ctrl_code]))
        print("TX CTRL:", ctrl_code)

        return

    # ----------------------------------
    # Regular printable keys
    # ----------------------------------

    if len(key) == 1:

        char = key

        # alphabetic case handling
        if char.isalpha():

            uppercase = caps_lock ^ shift_active

            if uppercase:
                char = char.upper()
            else:
                char = char.lower()

        # shifted symbols
        else:
            if shift_active and char in SHIFT_MAP:
                char = SHIFT_MAP[char]

        kaypro_uart.write(char)
        print("TX:", char)
        

# ==========================================================
# BUZZER
# ==========================================================

def beep(duration_ms=40):

    buzzer.value(1)
    time.sleep_ms(duration_ms)
    buzzer.value(0)
    
# ==========================================================
# MATRIX SCAN
# ==========================================================

def scan_matrix():
    """
    Scan the matrix and return a set of pressed keys.

    Returns:
        {(row, col), ...}
    """

    detected = set()

    for row_index, row in enumerate(rows):

        # Activate row
        row.value(0)

        # allow signals to settle
        time.sleep_us(SCAN_DELAY_US)

        # read columns
        for col_index, col in enumerate(cols):

            if col.value() == 0:
                detected.add((row_index, col_index))

        # deactivate row
        row.value(1)

    return detected


# ==========================================================
# SOFTWARE 2KRO LOCKOUT
# ==========================================================

def apply_2kro_lockout(keys):
    """
    Diode-less ghost prevention.

    Allow:
        0, 1, or 2 simultaneous keys

    Reject:
        3+ simultaneous keys
    """

    if len(keys) <= 2:
        return keys

    return set()


# ==========================================================
# DEBOUNCE
# ==========================================================

def update_debounce(raw_keys):

    global candidate_keys
    global stable_keys
    global last_change_time

    now = time.ticks_ms()

    # State changed
    if raw_keys != candidate_keys:
        candidate_keys = raw_keys
        last_change_time = now
        return stable_keys

    # Stable long enough?
    elapsed = time.ticks_diff(now, last_change_time)

    if elapsed >= DEBOUNCE_MS:
        stable_keys = candidate_keys

    return stable_keys


# ==========================================================
# MAIN LOOP
# ==========================================================

print("Keyboard scanner ready")

previous_keys = set()

while True:

    # Scan hardware
    raw_keys = scan_matrix()

    # Apply ghost prevention
    filtered_keys = apply_2kro_lockout(raw_keys)

    # Debounce
    current_keys = update_debounce(filtered_keys)

    # Detect changes
    new_keys = current_keys - previous_keys
    released_keys = previous_keys - current_keys

    # --------------------------------------------------
    # Handle key presses
    # --------------------------------------------------

    for row, col in sorted(new_keys):

        key = KEYMAP[row][col]

        if key is None:
            continue

        # SHIFT
        if key in ("LSHIFT", "RSHIFT"):
            shift_active = True
            continue

        # CTRL
        if key == "CTRL":
            ctrl_active = True
            continue

        # CAPS LOCK
        if key == "CAPS":
            caps_lock = not caps_lock

            # Update LED
            caps_led.value(caps_lock)

            print("CAPS:", caps_lock)

            beep(20)

            continue

        print("PRESS   {}".format(key))

        # Optional key click
        beep(5)

        send_key(key)

    # --------------------------------------------------
    # Handle key releases
    # --------------------------------------------------

    for row, col in sorted(released_keys):

        key = KEYMAP[row][col]

        if key is None:
            continue

        print("RELEASE {}".format(key))

        if key in ("LSHIFT", "RSHIFT"):
            shift_active = False

        elif key == "CTRL":
            ctrl_active = False

    previous_keys = current_keys

    time.sleep_ms(1)
